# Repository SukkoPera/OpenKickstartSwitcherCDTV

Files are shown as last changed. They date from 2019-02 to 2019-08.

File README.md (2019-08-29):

# OpenKickstartSwitcher CDTV Edition
OpenKickstartSwitcherCDTV is an Open Hardware Kickstart Switcher for the Commodore CDTV.

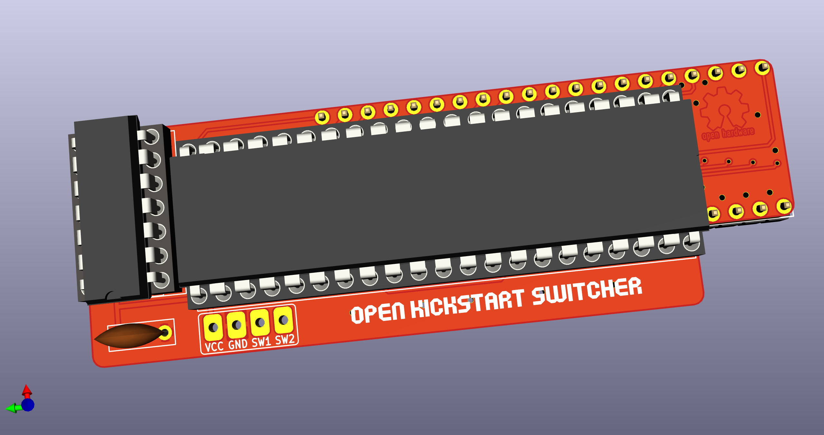
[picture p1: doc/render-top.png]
Board


### Summary
OpenKickstartSwitcherCDTV is a Kickstart switcher for the Commodore CDTV Entertainment System, based on [work by Henryk Richter](http://bax.comlab.uni-rostock.de/en/hardware/amiga500/kickstart-eprom/). It is basically the same circuit/board as [OpenKickstartSwitcher](https://github.com/SukkoPera/OpenKickstartSwitcher) but tailored in shape to the CDTV.

It allows switching among three or six different Kickstart images stored in an EPROM. The switching can be done through physical switches or by pressing the mouse/joystick buttons at power-up. The latter requires [an external add-on board](https://github.com/SukkoPera/OpenAmigaMouseTrigger) that is another project of mine.

### Assembly
Solder all components to the board. Starting with the smaller components might be a good idea, and make sure to solder the pin headers and resistor arrays before the socket. When soldering the resistor arrays, don't push them fully through the holes, as you will need to bend them against the board. No particular order is recommended for the remaining components.

The value of the two single resistors is not critical, 10k is recommended but probably any value between 5k and 50k will do.

My tests show that an SN74HC00 gate works fine. I don't recommend using parts from the *HC* series though, *HCT* or *LS* should be preferred.

The two resistor arrays are not always needed. You might get away without them, depending on the particular EPROM you are using: I have several EPROMs of the same model (but different production batches), and some need the resistors while others don't, so the only way to find out is actual testing. If you decide to install them, they must be of the *bussed* type and the recommended value is 4.7k. Be aware that these parts are polarized and must be installed with the right orientation!

### EPROM Selection and Switch Wiring
The adapter can be used with either 27C800 or 27C160 EPROMs. I recommend using *-100F1* EPROMs by ST, but access time is not critical: use 100ns or faster EPROMs if you can, but anything up to 150ns should work reliably.

#### 27C800
With a 27C800 EPROM, the adapter supports 2x256 KB Kickstart images (i.e.: up to version 1.3) and 1x512 KB image (version 2 and later).

To switch between ROMs, you will need two SPDT switches, connected to the SW1/SW2 pads and ground. A ground pad is available on the board, but any ground spot on the mainboard can be used as well, if easier to reach.

| ROM Image # | Size (KB) | SW1 | SW2 |
|---|---|-----|-----|
| 1 | 256 | LOW | LOW |
| 2 | 256 | HIGH| LOW |
| 3 | 512 |  x  | HIGH|

(x = Don't Care)

So, basically:
* If SW2 is HIGH, the 512 KB Kickstart image is selected, regardless of SW1.
* If SW2 is LOW, SW1 controls which one of the two 256 KB images is enabled: LOW selects the first one, and HIGH selects the second one.

You can also use a single ON-OFF-ON DPDT switch, just wire ground to the middle pins, SW1 and SW2 on one side and SW2 on the other.

As SW1/SW2 will both read as HIGH if left unconnected, the 512 KB Kickstart will be selected if no switches are wired.

You can fully ignore the A19 pad on the bottom side of the board, when using a 27C800 EPROM.

#### 27C160
With a 27C160 EPROM, the adapter supports up to 4x256 KB Kickstart images and 2x512 KB images.

You will need to solder an additional switch to the A19 pad on the bottom side of the board. VCC and GND pads are provided nearby so that you can also solder a pull-up/down resistor.

| ROM Image # | Size (KB) | SW1 | SW2 | A19 |
|---|---|-----|-----|-----|
| 1 | 256 | LOW | LOW | LOW |
| 2 | 256 | HIGH| LOW | LOW |
| 3 | 512 |  x  | HIGH| LOW |
| 4 | 256 | LOW | LOW | HIGH|
| 5 | 256 | HIGH| LOW | HIGH|
| 6 | 512 |  x  | HIGH| HIGH|

**IMPORTANT: ALWAYS TURN YOUR CDTV OFF BEFORE MOVING THE SELECTION SWITCHES.**

#### Flashing Notes
When flashing the EPROM, make sure that the ROM images you are using are exactly 262144 or 524288 bytes long, and just concatenate them. Take care to use the correct byte ordering, as the Amiga hardware expects 16-bit words to be stored in the *big-endian* format (which is NOT the format UAE expects them in, for the record). On Unix-like systems you can use the *conv=swab* option of *dd* to change the byte ordering.

27C800s and 27C160 are 42-pin EPROMs and most programmers only support chips up to 40 pins. This is the case with [the popular TL866 programmer](http://autoelectric.cn/EN/TL866_main.html), for instance. You can get around this limitation with an adapter PCB. There are at least two open designs of such an adapter:
* [One by keirff](https://github.com/keirf/PCB-Projects) (who, interestingly, has his own Kickstart Switcher)
* [And another one by gaggi](https://github.com/gaggi/27c160-tl866-adapter)

I have only used the latter and found it to be working fine.

### Installation
Once your OpenKickstartSwitcherCDTV is assembled and programmed, the rest of the installation should be pretty straightforward:
* Open your CDTV.
* Identify the Kickstart chip.
* Carefully remove it.
* Plug OpenKickstartSwitcher in its place, making sure to match the correct orientation.
* Drill some holes into the back of your CDTV (or wherever you prefer) and screw some switches in there.
* Solder wires to switches.
* Close your CDTV.

Of course, if you use OpenAmigaMouseTrigger there is no need to drill any holes.

### DiagROM
The excellent [DiagROM by chucky](http://www.diagrom.com) can be used with OpenKickstartSwitcherCDTV, even though not all functions work on a CDTV.

Normally it is distributed as a 512 KB image, but most of the space is unused, so I have created a 256 KB version of DiagROM 1.0 by simply truncating the image. It is **NOT GUARANTEED TO WORK**, but it looks fine to me. It can be [downloaded here](https://github.com/SukkoPera/OpenKickstartSwitcher/files/1777856/diagrom-256k.zip).

### License
The OpenKickstartSwitcherCDTV documentation, including the design itself, is copyright &copy; SukkoPera 2018-2019.

OpenKickstartSwitcherCDTV is Open Hardware licensed under the [CERN OHL v. 1.2](http://ohwr.org/cernohl).

You may redistribute and modify this documentation under the terms of the CERN OHL v.1.2. This documentation is distributed *as is* and WITHOUT ANY EXPRESS OR IMPLIED WARRANTIES whatsoever with respect to its functionality, operability or use, including, without limitation, any implied warranties OF MERCHANTABILITY, SATISFACTORY QUALITY, FITNESS FOR A PARTICULAR PURPOSE or infringement. We expressly disclaim any liability whatsoever for any direct, indirect, consequential, incidental or special damages, including, without limitation, lost revenues, lost profits, losses resulting from business interruption or loss of data, regardless of the form of action or legal theory under which the liability may be asserted, even if advised of the possibility or likelihood of such damages.

A copy of the full license is included in file [LICENSE.pdf](LICENSE.pdf), please refer to it for applicable conditions. In order to properly deal with its terms, please see file [LICENSE_HOWTO.pdf](LICENSE_HOWTO.pdf).

The contact points for information about manufactured Products (see section 4.2) are listed in file [PRODUCT.md](PRODUCT.md).

Any modifications made by Licensees (see section 3.4.b) shall be recorded in file [CHANGES.md](CHANGES.md).

The Documentation Location of the original project is https://github.com/SukkoPera/OpenKickstartSwitcherCDTV/.

### Support the Project
Since the project is open you are free to get the PCBs made by your preferred manufacturer, however in case you want to support the development, you can order them from PCBWay through this link:

PCB from PCBWay (https://www.pcbway.com/project/shareproject/OpenKickstartSwitcherCDTV_V1.html)

You get cheap, professionally-made and good quality PCBs, I get some credit that will help with this and [other projects](https://www.pcbway.com/project/member/shareproject/?bmbid=41100). You won't even have to worry about the various PCB options, it's all pre-configured for you!

Also, if you still have to register to that site, [you can use this link](https://www.pcbway.com/setinvite.aspx?inviteid=41100) to get some bonus initial credit (and yield me some more).

Again, if you want to use another manufacturer, feel free to, don't feel obligated :). But then you can buy me a coffee if you want:

<a href='https://ko-fi.com/L3L0U18L' target='_blank'>Buy Me a Coffee at ko-fi.com</a>

### Get Help
If you need help or have questions, you can join [the official Telegram group](https://t.me/joinchat/HUHdWBC9J9JnYIrvTYfZmg).

### Thanks
Thanks to Henryk Richter, Aldo PRS and [screwbreaker](https://github.com/screwbreaker).

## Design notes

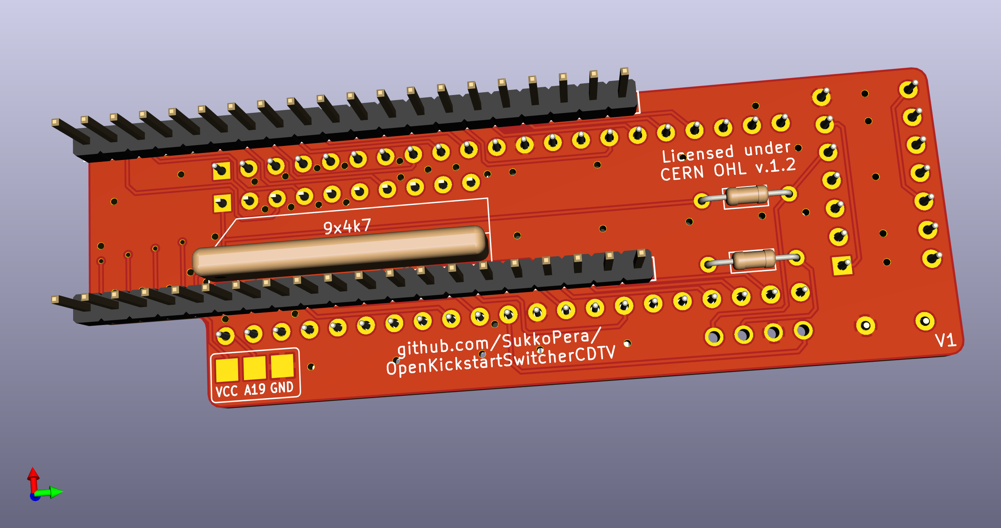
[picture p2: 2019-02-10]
doc/render-bottom.png

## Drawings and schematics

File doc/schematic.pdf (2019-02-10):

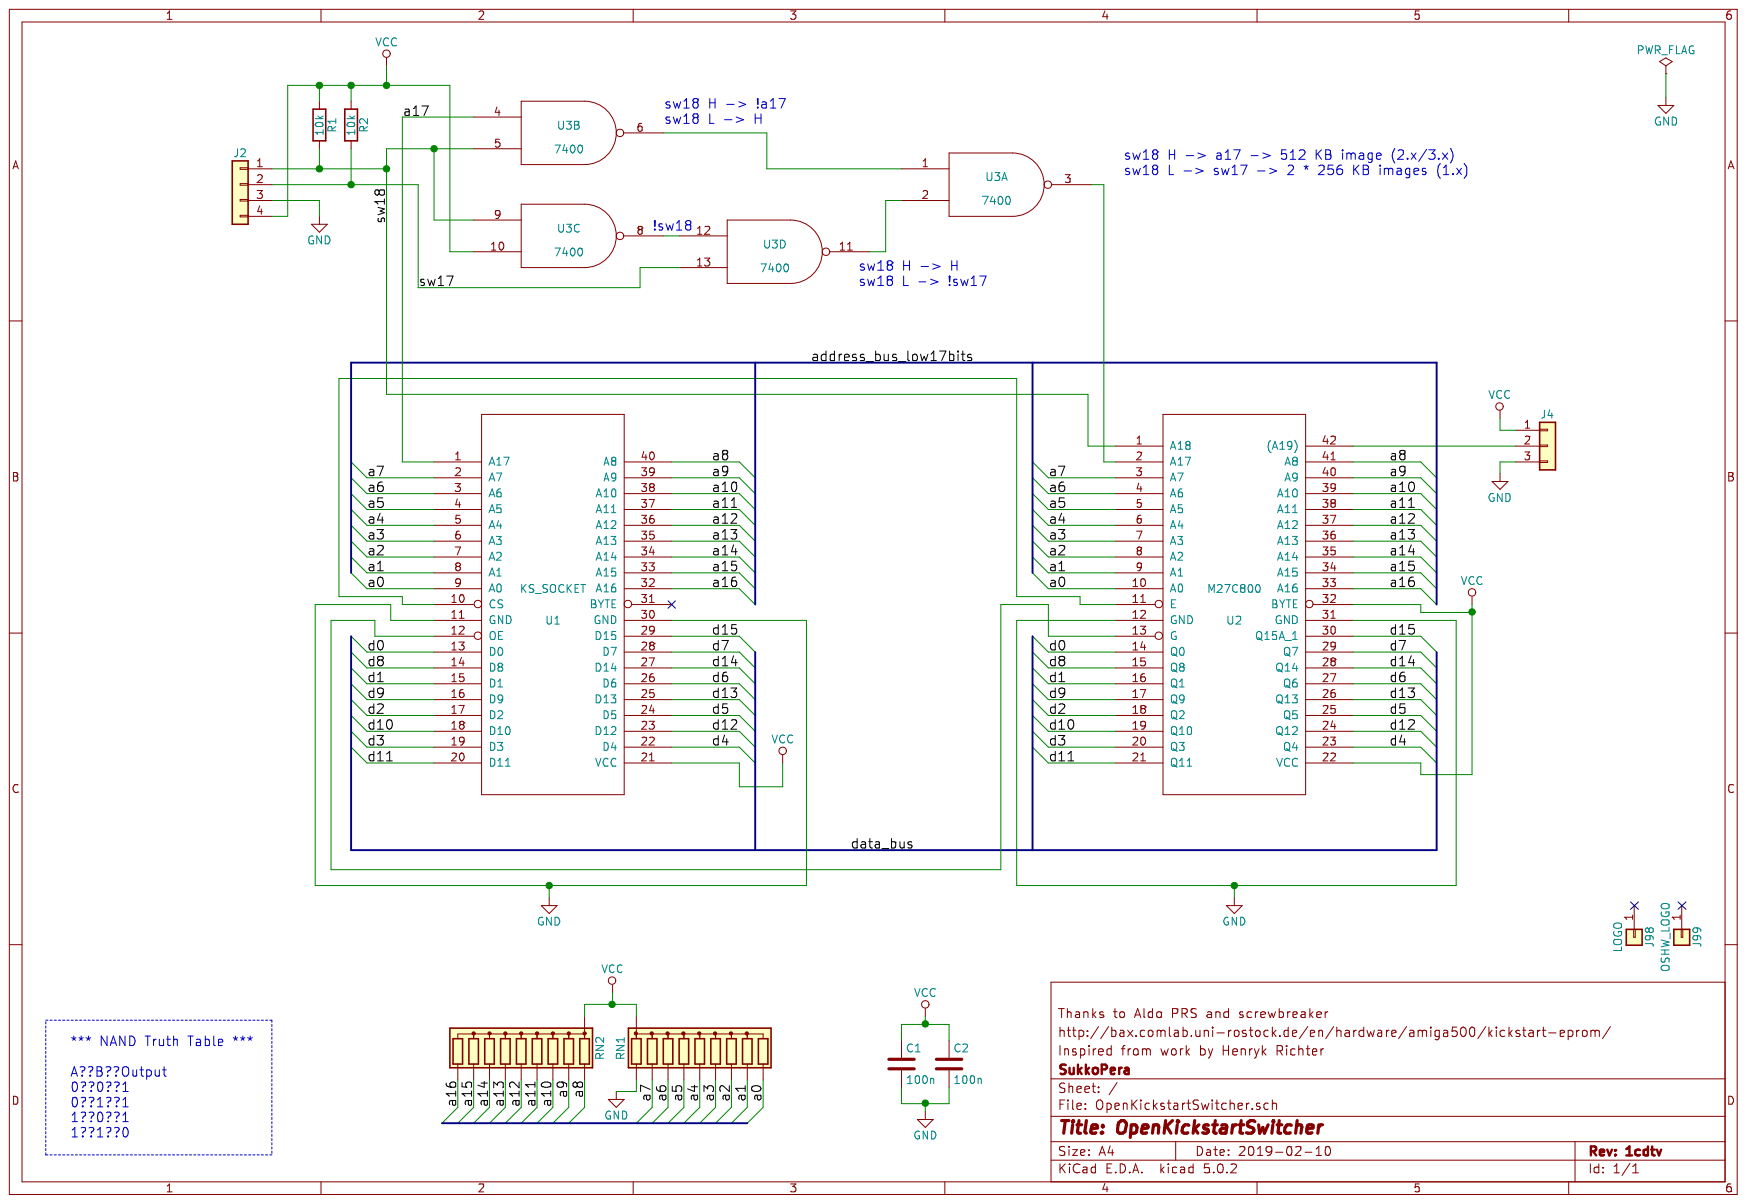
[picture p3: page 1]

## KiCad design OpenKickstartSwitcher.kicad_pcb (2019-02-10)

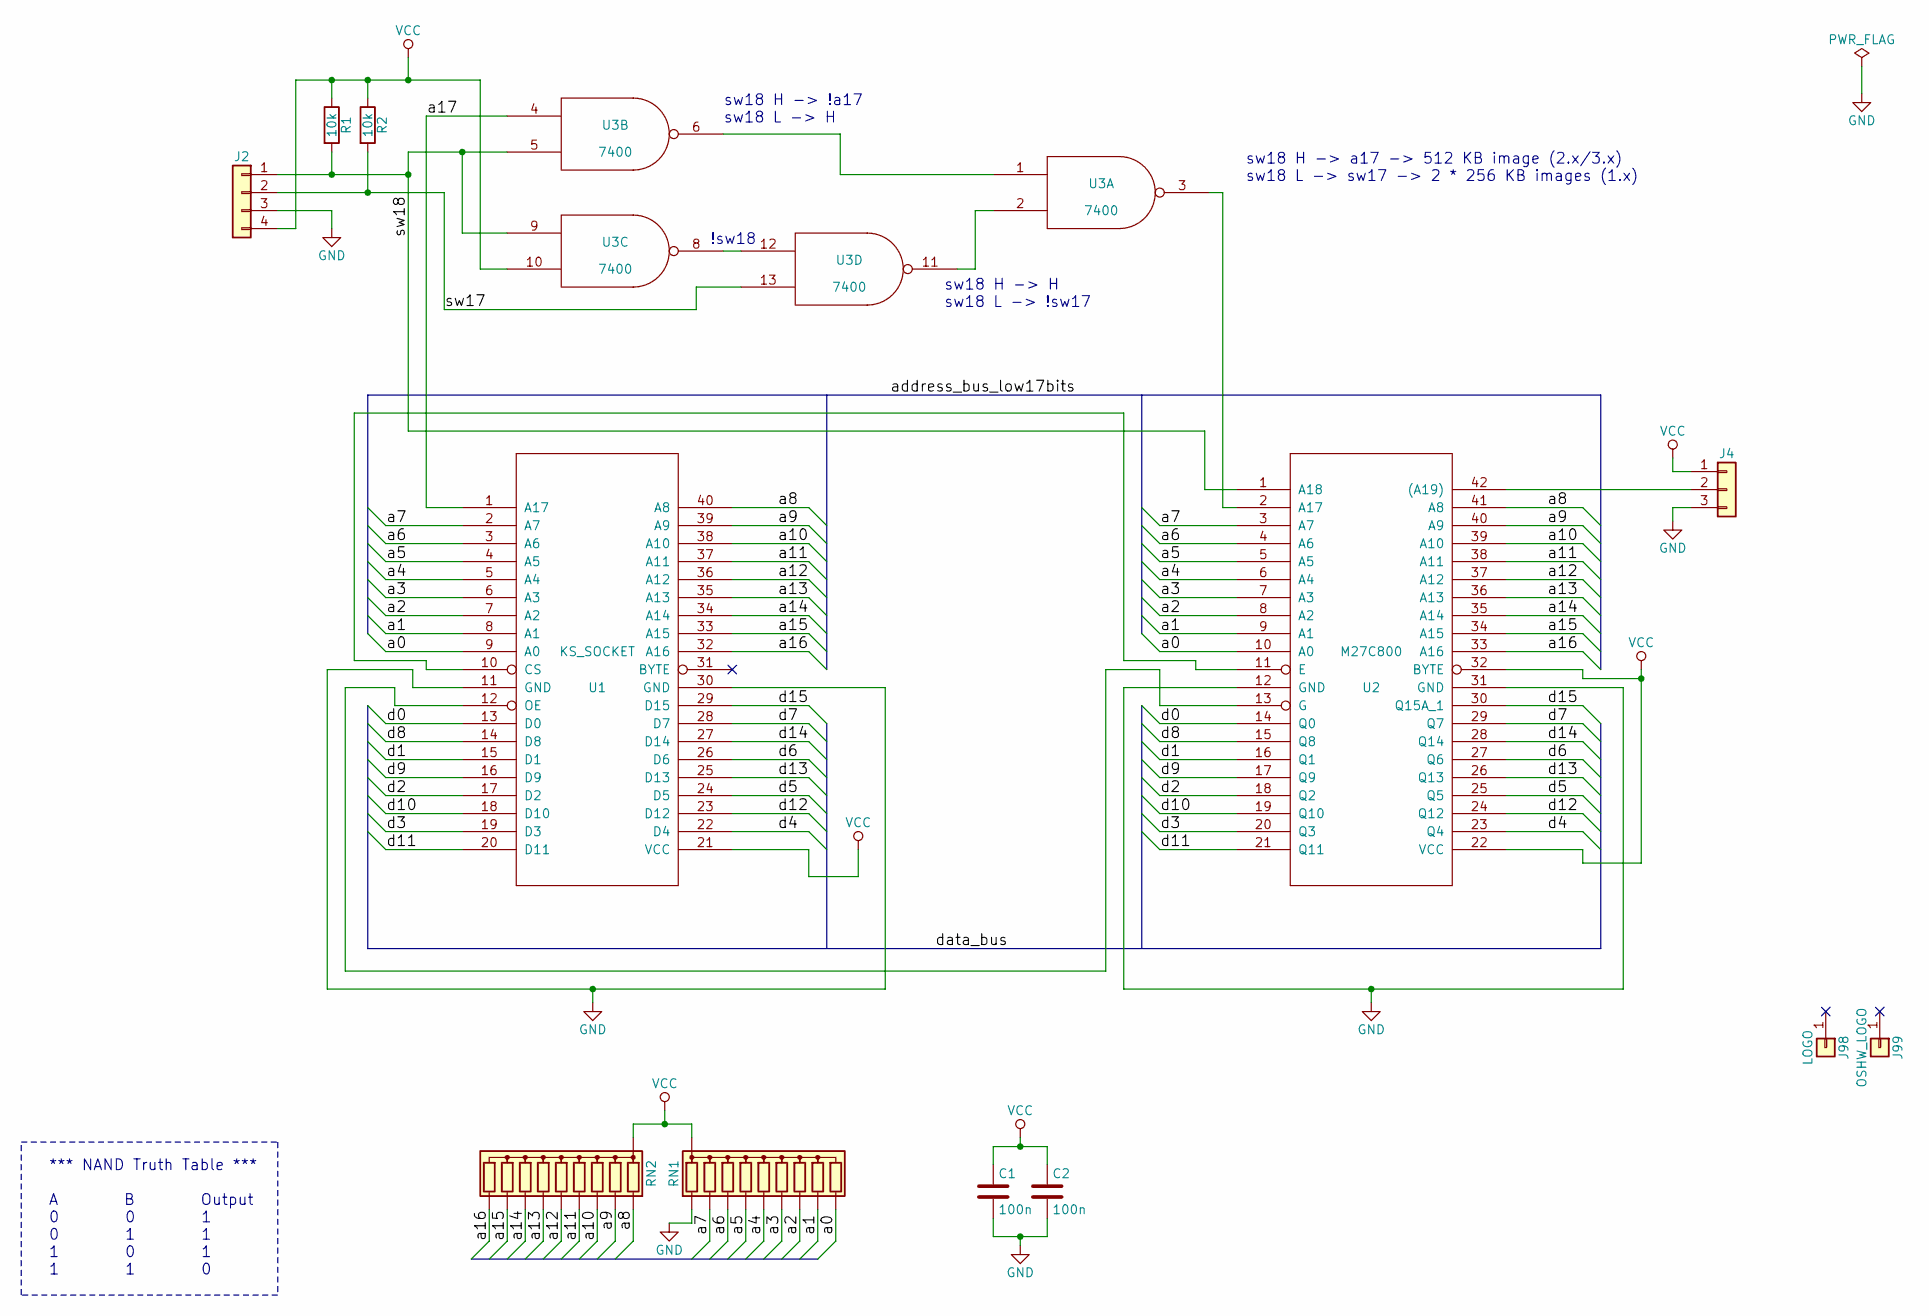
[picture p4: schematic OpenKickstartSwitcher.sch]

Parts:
C1, C2: 100n; C_Disc_D7.0mm_W2.5mm_P5.00mm
J2: Conn_01x04; Solderable_PinHeader_1x04
J4: Conn_01x03; SolderJumper
J98: LOGO; logo
J99: OSHW_LOGO; Logo_copper_OSHW_6x6mm
R1, R2: 10k; R_Axial_DIN0204_L3.6mm_D1.6mm_P7.62mm_Horizontal
RN1, RN2: 4.7k; R_Array_SIP10_OnSide
U1: KS_SOCKET; DIP-40_DualHeaderStrips
U2: M27C800; DIP-42_Socket
U3: 7400; DIP-14_W7.62mm_Socket

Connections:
/a0: RN1.10 (R9), U1.9 (A0), U2.10 (A0)
/a1: RN1.9 (R8), U1.8 (A1), U2.9 (A1)
/a2: RN1.8 (R7), U1.7 (A2), U2.8 (A2)
/a3: RN1.7 (R6), U1.6 (A3), U2.7 (A3)
/a4: RN1.6 (R5), U1.5 (A4), U2.6 (A4)
/a5: RN1.5 (R4), U1.4 (A5), U2.5 (A5)
/a6: RN1.4 (R3), U1.3 (A6), U2.4 (A6)
/a7: RN1.3 (R2), U1.2 (A7), U2.3 (A7)
/a8: RN2.2 (R1), U1.40 (A8), U2.41 (A8)
/a9: RN2.3 (R2), U1.39 (A9), U2.40 (A9)
/a10: RN2.4 (R3), U1.38 (A10), U2.39 (A10)
/a11: RN2.5 (R4), U1.37 (A11), U2.38 (A11)
/a12: RN2.6 (R5), U1.36 (A12), U2.37 (A12)
/a13: RN2.7 (R6), U1.35 (A13), U2.36 (A13)
/a14: RN2.8 (R7), U1.34 (A14), U2.35 (A14)
/a15: RN2.9 (R8), U1.33 (A15), U2.34 (A15)
/a16: RN2.10 (R9), U1.32 (A16), U2.33 (A16)
/a17: U1.1 (A17), U3.4
/d0: U1.13 (D0), U2.14 (Q0)
/d1: U1.15 (D1), U2.16 (Q1)
/d2: U1.17 (D2), U2.18 (Q2)
/d3: U1.19 (D3), U2.20 (Q3)
/d4: U1.22 (D4), U2.23 (Q4)
/d5: U1.24 (D5), U2.25 (Q5)
/d6: U1.26 (D6), U2.27 (Q6)
/d7: U1.28 (D7), U2.29 (Q7)
/d8: U1.14 (D8), U2.15 (Q8)
/d9: U1.16 (D9), U2.17 (Q9)
/d10: U1.18 (D10), U2.19 (Q10)
/d11: U1.20 (D11), U2.21 (Q11)
/d12: U1.23 (D12), U2.24 (Q12)
/d13: U1.25 (D13), U2.26 (Q13)
/d14: U1.27 (D14), U2.28 (Q14)
/d15: U1.29 (D15), U2.30 (Q15A_1)
/sw17: J2.2, R2.2, U3.13
/sw18: J2.1, R1.2, U2.1 (A18), U3.5, U3.9
GND: C1.2, C2.2, J2.3, J4.3, RN1.2 (R1), U1.11 (GND), U1.30 (GND), U2.12 (GND), U2.31 (GND), U3.7 (GND)
unnamed: J4.2, U2.42 ((A19))
unnamed: U1.10 (CS), U2.11 (E)
unnamed: U1.12 (OE), U2.13 (G)
unnamed: U2.2 (A17), U3.3
unnamed: U3.1, U3.6
unnamed: U3.2, U3.11
unnamed: U3.8, U3.12
VCC: C1.1, C2.1, J2.4, J4.1, R1.1, R2.1, RN1.1 (common), RN2.1 (common), U1.21 (VCC), U2.22 (VCC), U2.32 (BYTE), U3.10, U3.14 (VCC)

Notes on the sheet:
sw18 H -> a17 -> 512 KB image (2.x/3.x) sw18 L -> sw17 -> 2 * 256 KB images (1.x)
!sw18
sw18 H -> !a17 sw18 L -> H
sw18 H -> H sw18 L -> !sw17
*** NAND Truth Table *** A B Output 0 0 1 0 1 1 1 0 1 1 1 0

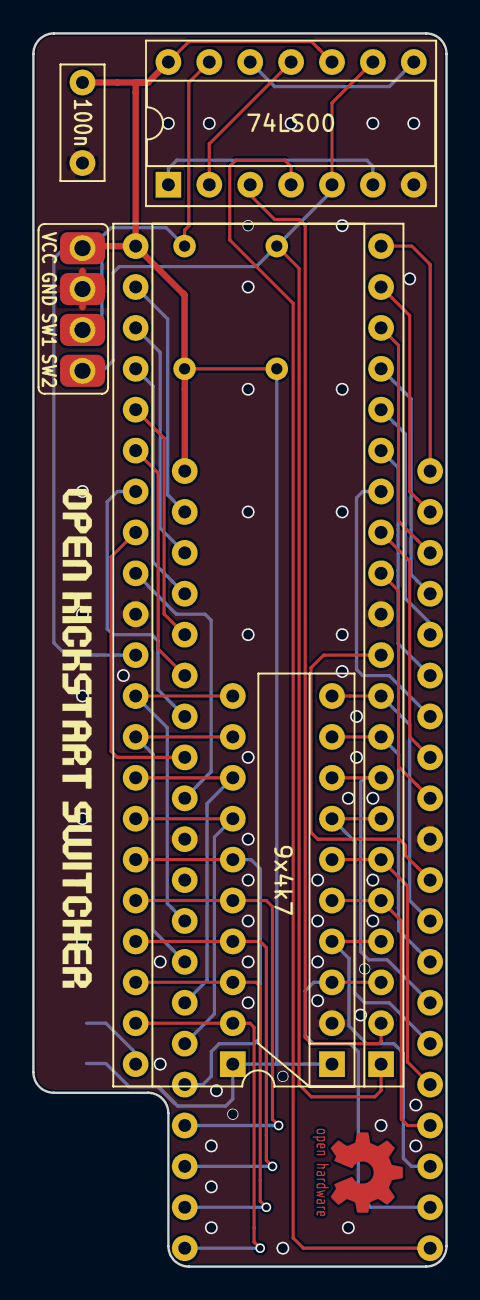
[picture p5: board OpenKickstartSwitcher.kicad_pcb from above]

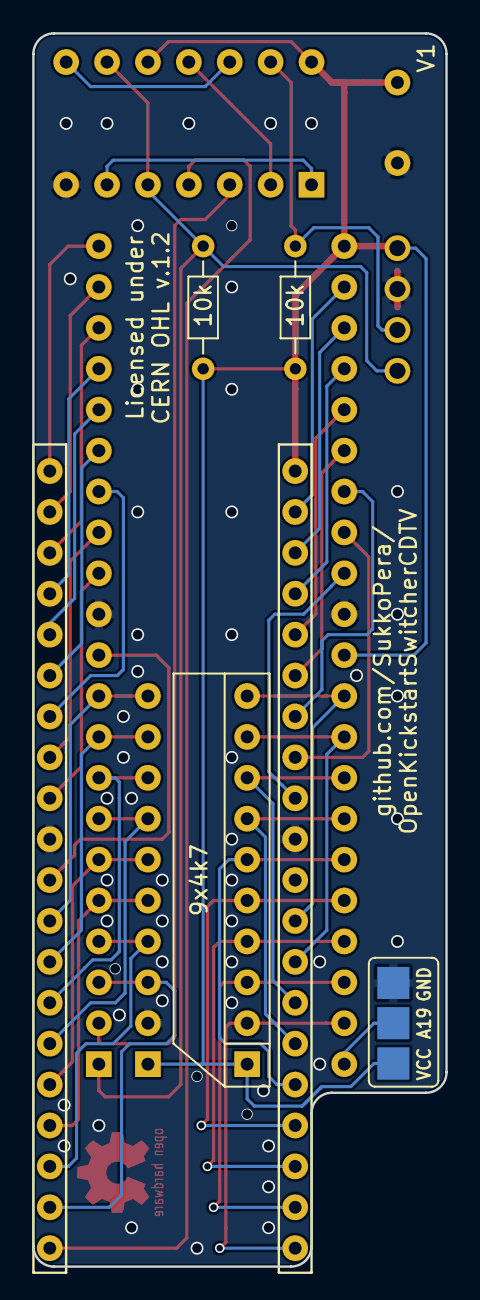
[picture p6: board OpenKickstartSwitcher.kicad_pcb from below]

Board: 2 copper layers, 25.7 x 76.6 mm, 12 parts (4 on the bottom side), 45 nets.

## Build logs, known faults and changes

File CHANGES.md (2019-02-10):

## CHANGES

Any modifications to the OpenKickstartSwitcherCDTV design and documentation made by any Licensee MUST be noted in this file, as per *section 3.4.b* of the [license](LICENSE.pdf).

### (Date) - (Author)
(Description)
